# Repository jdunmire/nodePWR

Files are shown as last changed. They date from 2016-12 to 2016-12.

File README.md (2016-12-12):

TLPHnode
=========
This is a [KiCad](http://kicad-pcb.org/) project for power supply and
breakout board to be used with the TLPHnode.

Additional information about the TLPHnode can be found at the 
[Sensor Nodes](http://sensornodeinfo.rockingdlabs.com) website.

Copyright Jerry Dunmire 2016.

This documentation describes Open Hardware and is licensed under the
CERN OHL v. 1.2.

You may redistribute and modify this documentation under the terms of
the CERN OHL v.1.2. (LICENSE.txt). This documentation is distributed
WITHOUT ANY EXPRESS OR IMPLIED WARRANTY, INCLUDING OF MERCHANTABILITY,
SATISFACTORY QUALITY AND FITNESS FOR A PARTICULAR PURPOSE. Please see
the CERN OHL v.1.2 for applicable conditions

Guidelines on how to apply the CERN OHL v1.2 are in the
cern_ohl_v_1_2_howto.pdf file.

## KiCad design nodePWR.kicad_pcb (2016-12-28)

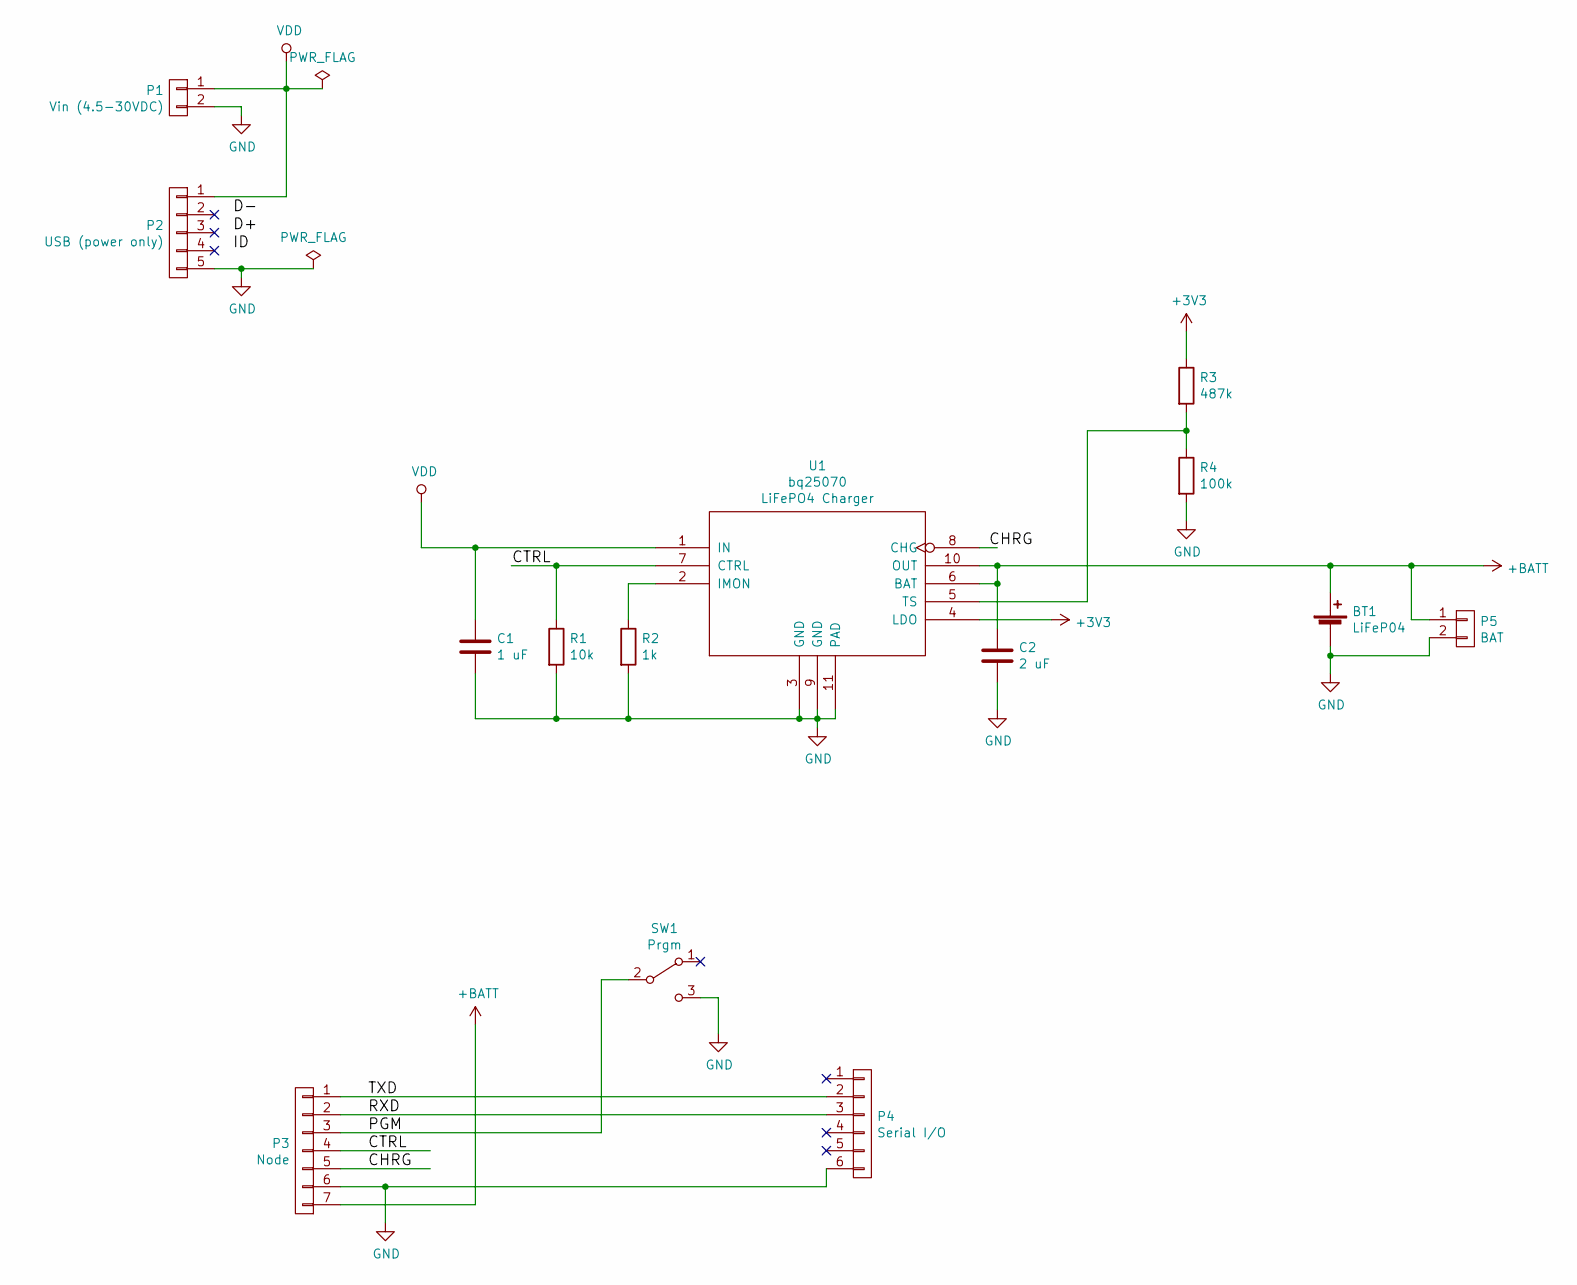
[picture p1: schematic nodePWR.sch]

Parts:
BT1: LiFeP04; JST_PH_S2B-PH-SM4-TB_02x2.00mm_Angled
C1: 1 uF; C_0603
C2: 2 uF; C_0603
P1: Vin (4.5-30VDC); Pin_Header_Straight_1x02
P2: USB (power only); USB_Micro-B_10103594-0001LF
P3: Node; FPC_conn-7_8x4.9mm_Pitch0.5mm
P4: Serial I/O; Pin_Header_Straight_1x06
P5: BAT; Pin_Header_Straight_1x02
R1: 10k; R_0603
R2: 1k; R_0603
R3: 487k; R_0603
R4: 100k; R_0603
SW1: Prgm; SW_SPDT_PCM12
U1: bq25070; bq25070_DQC_10-DQC10_P84X2P4

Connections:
+3V3: R3.1, U1.4 (LDO)
+BATT: BT1.1 (+), C2.1, P3.7, P5.1, U1.6 (BAT), U1.10 (OUT)
/CHRG: P3.5, U1.8 (CHG)
/CTRL: P3.4, R1.1, U1.7 (CTRL)
/PGM: P3.3, SW1.2 (B)
/RXD: P3.2, P4.3
/TXD: P3.1, P4.2
GND: BT1.2 (-), C1.2, C2.2, P1.2, P2.5, P3.6, P4.6, P5.2, R1.2, R2.2, R4.2, SW1.3 (C), U1.3 (GND), U1.9 (GND), U1.11 (PAD)
unnamed: R2.1, U1.2 (IMON)
unnamed: R3.2, R4.1, U1.5 (TS)
VDD: C1.1, P1.1, P2.1, U1.1 (IN)

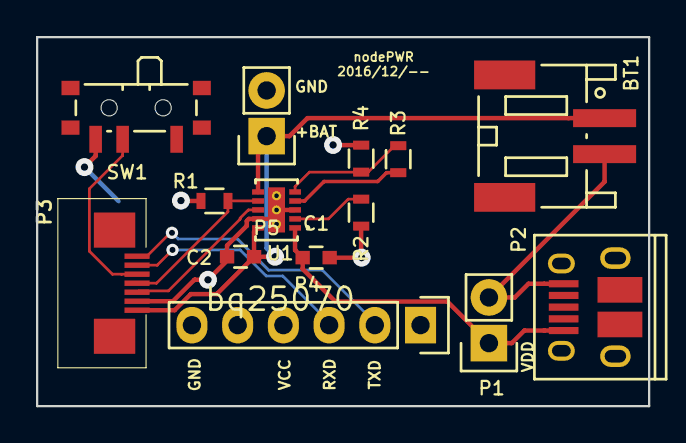
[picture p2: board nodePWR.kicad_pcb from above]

Board: 2 copper layers, 34.0 x 20.5 mm, 14 parts (0 on the bottom side), 11 nets.

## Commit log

2016-12-12 Setup an empty KiCad project
    On branch master
    Changes to be committed:
    new file: .gitignore
    new file: CAM/README.md
    new file: LICENSE.txt
    new file: PRODUCT.txt
    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
    [nodePWR.kicad_pcb, nodePWR.sch]
2016-12-13 Checkpoint - starting PCB
    modified: nodePWR-cache.lib
    modified: nodePWR.kicad_pcb
    modified: nodePWR.pro
    modified: nodePWR.sch
    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
    [nodePWR.kicad_pcb, nodePWR.sch]
2016-12-13 Use TI/Ultra-librarian footprint for bq25070
    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
    [nodePWR.kicad_pcb, nodePWR.sch]
2016-12-13 Check-point: parts placed
    - board size 20.5mm high to match TLPNode
    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
    [nodePWR.kicad_pcb]
2016-12-13 Fix bq25070 footprint
    - vias were numbered separately and therefore not connnected to
    ground. Footprint was changed so that the pad and the vias all
    are pin 11.
    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
    [nodePWR.kicad_pcb]
2016-12-13 Make board cut a polygon
    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
    [nodePWR.kicad_pcb]
2016-12-14 Checkpoint: routed, no DRC errors
    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
    [nodePWR.kicad_pcb]
2016-12-14 Make changes to allow for an enclosure
    - move USB closer to PCB edge
    - Rotate BT1 so that connector can be used when there is an
    enclosure.
    - Add pins to solder in a battery.
    - change serial I/O header to veritical.
    [nodePWR.kicad_pcb, nodePWR.sch]
2016-12-15 Cleanup silk screen
    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
    [nodePWR.kicad_pcb]
2016-12-15 Clean-up tracks and vias
    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
    [nodePWR.kicad_pcb]
2016-12-16 Change to standard resistor value
    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
    [nodePWR.sch]
2016-12-23 No intentional changes
    - I think the changes here are a side effect of an update to KiCAD.
    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
2016-12-28 Checkpoint - remove routing
    - preparing to add 7-pin connector and signals to the TLPHnode
    board.
    On branch addChargerSignals
    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
    [nodePWR.kicad_pcb]
2016-12-28 Checkpoint - replaced 6pin conn with 7pin
    - Changed signals to provide charge controll and monitoring on P3
    [nodePWR.sch]
2016-12-28 Checkpoint - Re-annotate, fix DRC warnings
    - Renumbered all anotations to eliminate gaps
    - Marked VDD and GND as power
    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
    [nodePWR.sch]
2016-12-28 Add footprint for 7pin
    modified: nodePWR.net
    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
    [nodePWR.sch]
2016-12-28 Checkpoint - routed
    - passes DRC
    [nodePWR.kicad_pcb]

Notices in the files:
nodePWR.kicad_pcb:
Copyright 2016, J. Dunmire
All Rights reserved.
